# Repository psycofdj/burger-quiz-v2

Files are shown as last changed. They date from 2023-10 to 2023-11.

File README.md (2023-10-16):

<!-- markdown-toc start - Don't edit this section. Run M-x markdown-toc-refresh-toc -->
**Table of Contents**

- [Hardware](#hardware)
    - [Global Schematics](#global-schematics)
    - [Ready to solder PCB](#ready-to-solder-pcb)
- [Construction](#construction)
    - [Global design](#global-design)
    - [Components](#components)
- [Installation](#installation)

<!-- markdown-toc end -->

## Hardware

### Global Schematics

Sources for global schematics are [here](./kicad/board)

board global schematic

### Ready to solder PCB

Sources for ready-to-solder PCB are [here](./kicad/pcb)

pcb pcb schematic

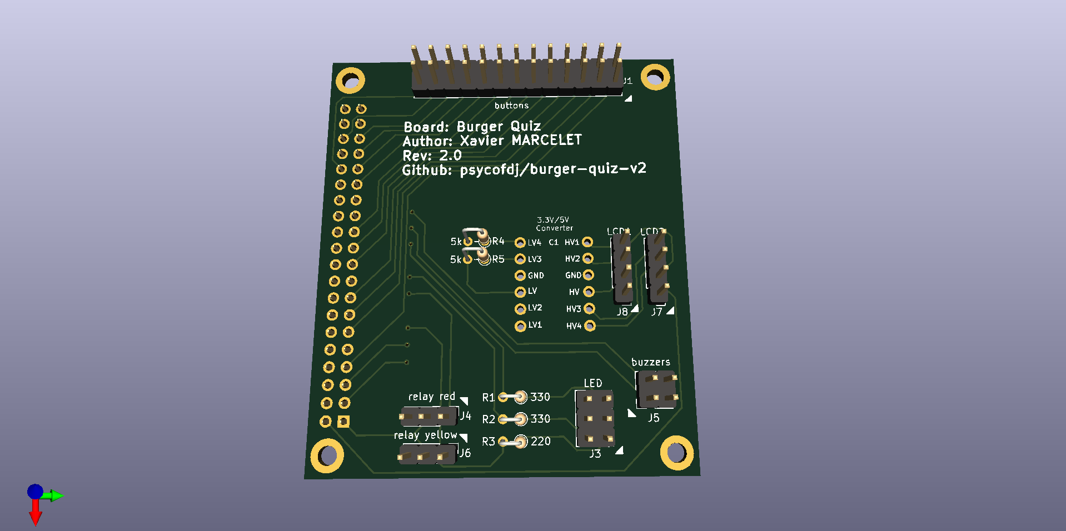
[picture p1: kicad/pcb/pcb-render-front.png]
pcb-front pcb render front


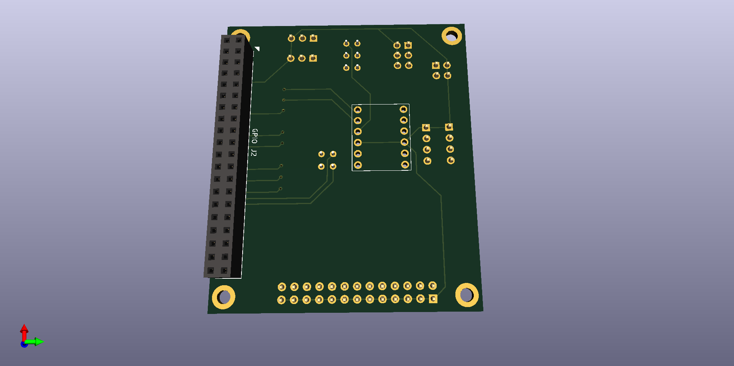
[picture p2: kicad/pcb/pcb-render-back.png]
pcb-back pcb render front


## Construction

### Global design

Sources for desk design are [here](./sketcup)

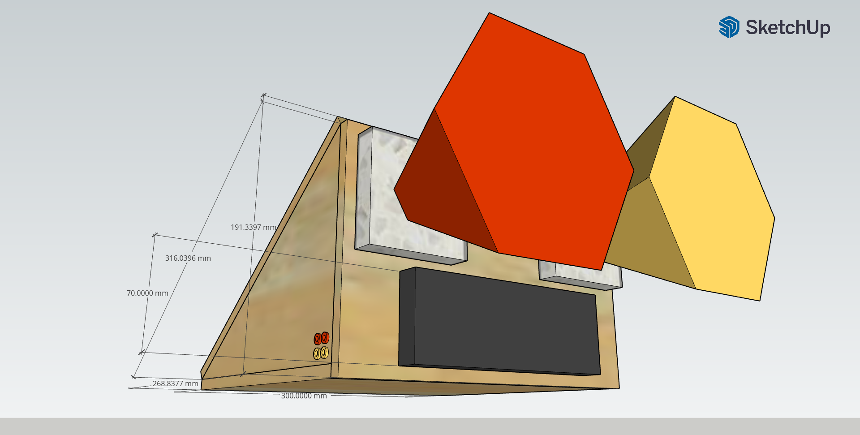
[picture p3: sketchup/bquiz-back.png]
back

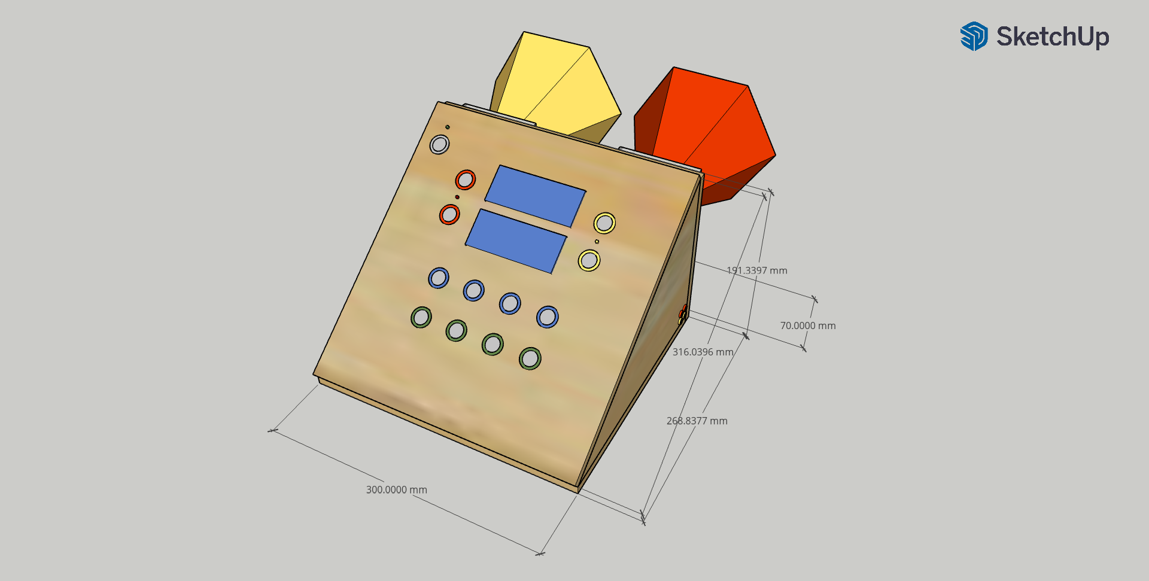
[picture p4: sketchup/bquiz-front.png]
front

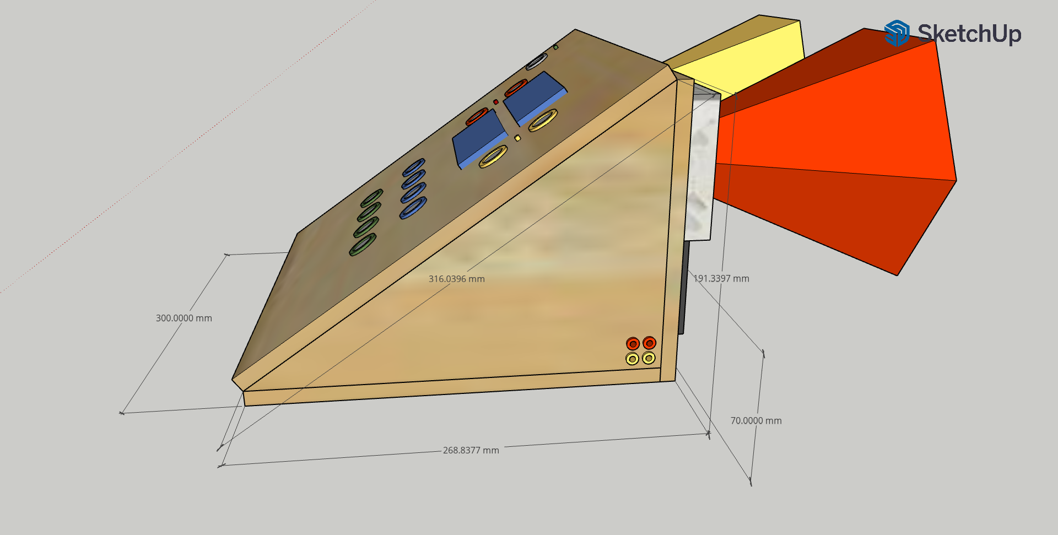
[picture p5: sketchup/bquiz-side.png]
side

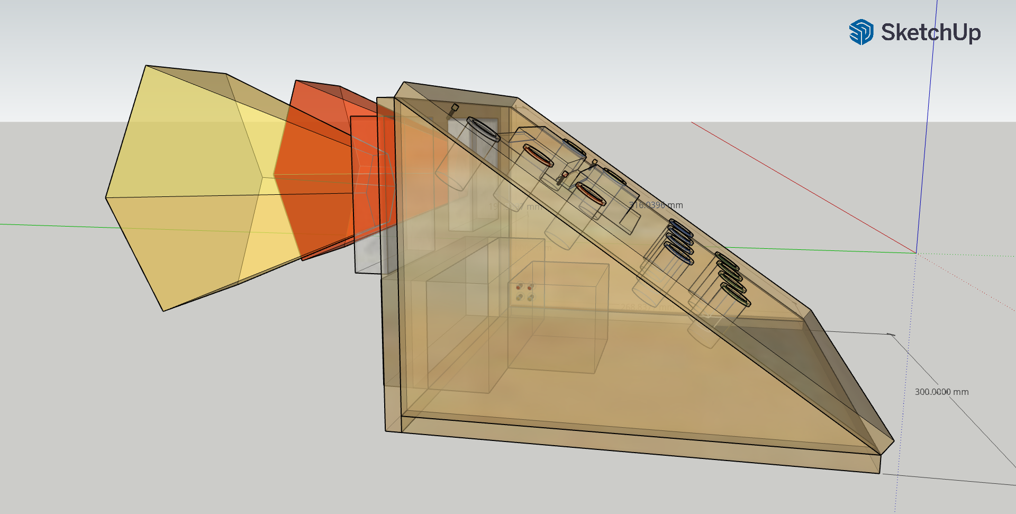
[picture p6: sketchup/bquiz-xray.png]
xray


### Components

- 22.99€,  3 x LCD displays: https://www.amazon.fr/dp/B07V5K3ZVB?ref=ppx_yo2ov_dt_b_product_details&th=1
- 8.99€,  15 x 3.3V to 5V signal converter: https://www.amazon.fr/dp/B082F6BSB5?psc=1&ref=ppx_yo2ov_dt_b_product_details
- 8.58€,   1 x LED kit: https://www.amazon.fr/dp/B08S2W74K7?ref=ppx_yo2ov_dt_b_product_details&th=1
- 10.99€,  1 x Flat cable: https://www.amazon.fr/dp/B082WZC56B?psc=1&ref=ppx_yo2ov_dt_b_product_details
- 11.99€,  1 x Connector kit: https://www.amazon.fr/dp/B089LZ14WB?psc=1&ref=ppx_yo2ov_dt_b_product_details
- 66.50€,  1 x Rasberry PI 4 model B: https://www.kubii.com/en/raspberry-pi-boards/2772-raspberry-pi-4-model-b-4gb-3272496309333.html
- 7,49 €,  1 x 16GB microSD: https://www.amazon.fr/dp/B07DVG12SF?psc=1&ref=ppx_yo2ov_dt_b_product_details
- 18.59€,  1 x USB Speader: https://www.amazon.fr/Umitive-Haut-Parleur-dOrdinateur-Compatibilit%C3%A9-Antid%C3%A9rapante/dp/B08JTRML6R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
- 38,27€, 13 x Custom made 5v LED push switches: https://fr.aliexpress.com/item/4000098893464.html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

## Installation

Sources for software are [here](./bquiz)

- Enable primary I2C port (/dev/i2c-1)

```
$ sudo raspi-config
(select 3. Interface options)
(select I5. I2C)
(select yes)
```

- Enable secondary I2C port (/dev/i2c-0)

```
cat /boot/config.txt
...
dtparam=i2c_arm=on
dtparam=i2c_vc=on
...
```

- Check I2C ports

```
 # package to test gpio port
 sudo apt install i2c-dev i2c-tools

 # check i2c ports, should have 27 on
 i2cdetect -y 1
 i2cdetect -y 0
```

- Install sound support

```
 sudo apt-get install pulseaudio pulseaudio-utils python3-vlc
```

- Configure default pulseaudio sink

```
 pactl set-default-sink alsa_output.usb-C-Media_Electronics_Inc._USB_Audio_Device-00.analog-stereo
```

- Install software as user startup service

```
 # install bquiz cli to ~/.local/bin
 python3 -m pip install .

 # install user systemd unit
 mkdir -p ~/.config/systemd/user
 ln -s $(pwd)/systemd/user/bquiz.service ~/.config/systemd/
 systemctl --user enable bquiz.service

 # run bquiz
 systemctl --user start bquiz.service
```

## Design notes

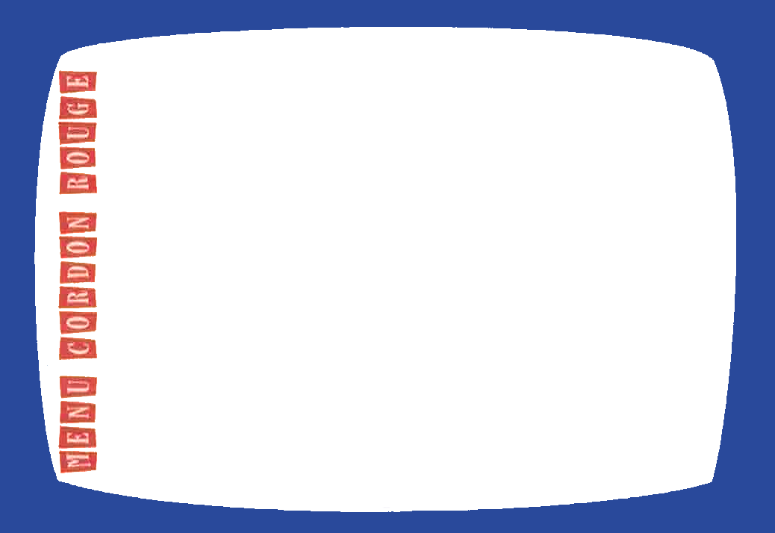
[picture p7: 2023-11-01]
bquiz/resources/menus-rouge-back.png

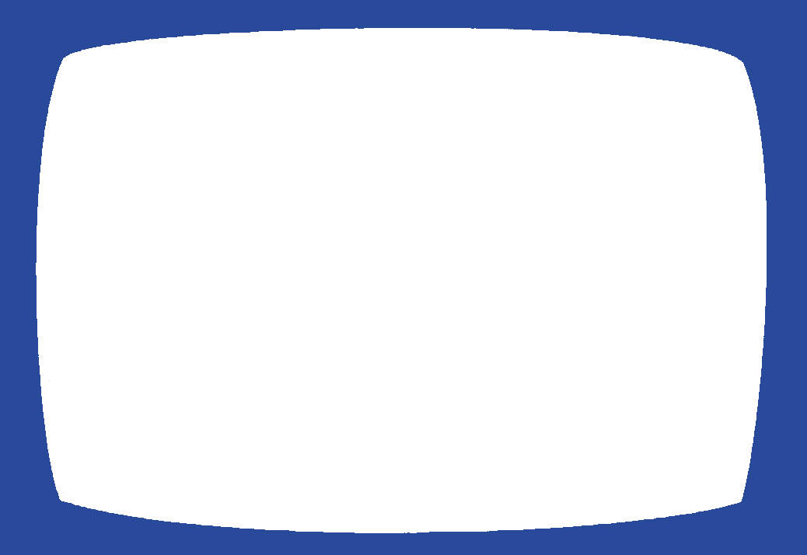
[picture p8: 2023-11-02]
bquiz/resources/base.png

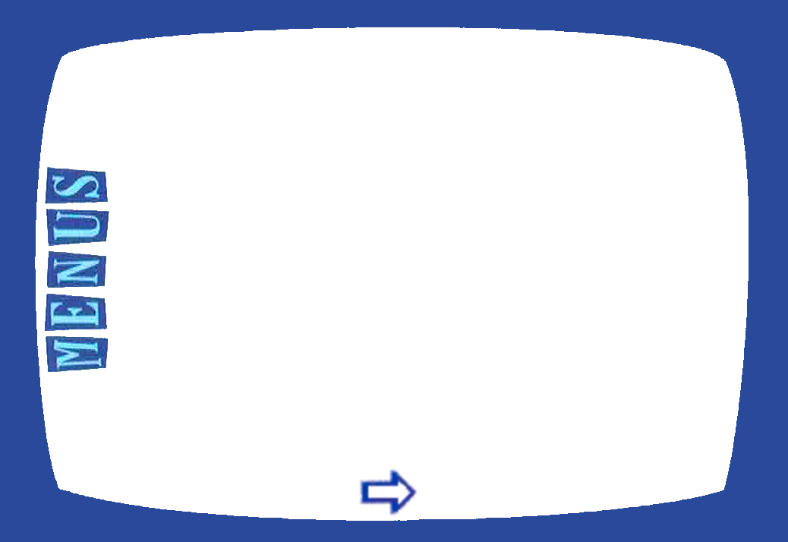
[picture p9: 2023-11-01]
bquiz/resources/menus-back-arrow.png

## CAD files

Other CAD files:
sketchup/bquiz.skp

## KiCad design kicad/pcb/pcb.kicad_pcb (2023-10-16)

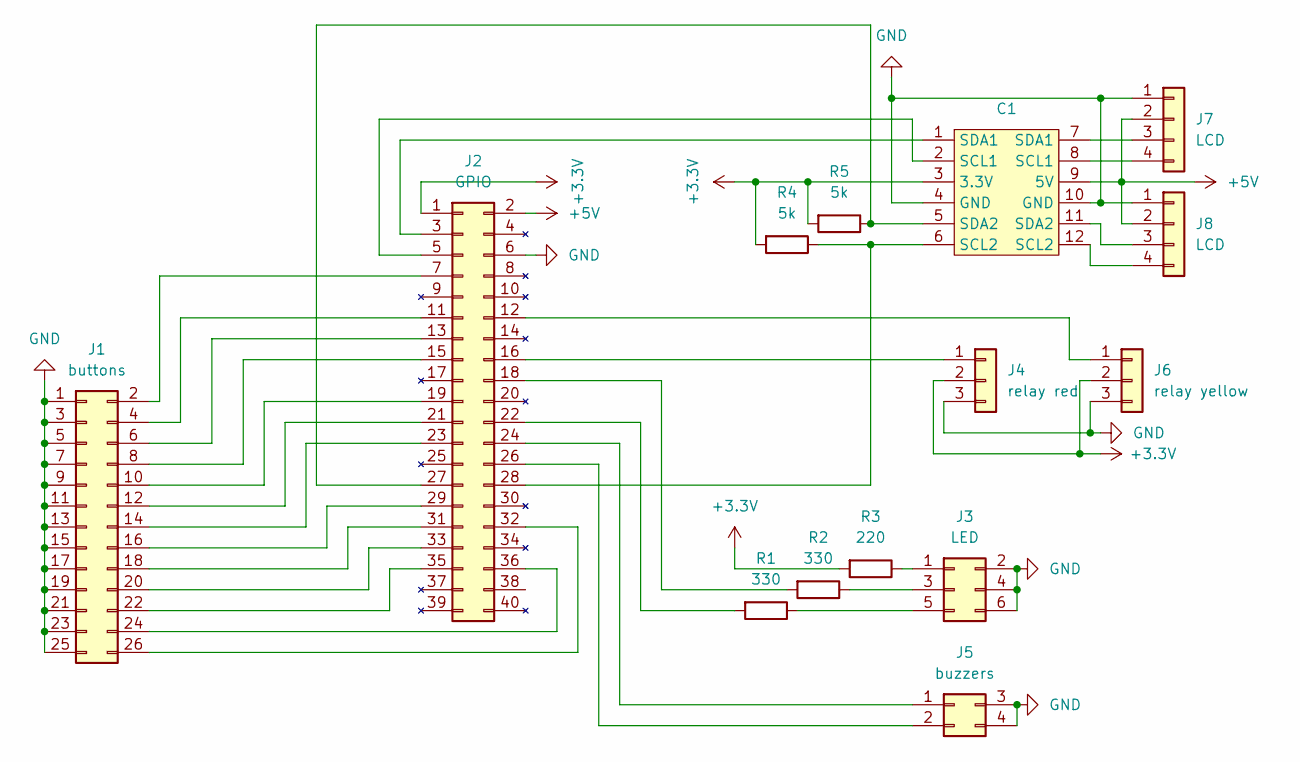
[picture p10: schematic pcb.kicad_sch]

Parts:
C1: Converter_3.3v_5v_i2c
J1: buttons; PinHeader_2x13_P2.54mm_Vertical
J2: GPIO; PinSocket_2x20_P2.54mm_Vertical
J3: LED; PinHeader_2x03_P2.54mm_Vertical
J4: relay red; PinHeader_1x03_P2.54mm_Vertical
J5: buzzers; PinHeader_2x02_P2.54mm_Vertical
J6: relay yellow; PinHeader_1x03_P2.54mm_Vertical
J7, J8: LCD; PinHeader_1x04_P2.54mm_Vertical
R1, R2: 330; R_Axial_DIN0204_L3.6mm_D1.6mm_P2.54mm_Vertical
R3: 220; R_Axial_DIN0204_L3.6mm_D1.6mm_P2.54mm_Vertical
R4, R5: 5k; R_Axial_DIN0204_L3.6mm_D1.6mm_P2.54mm_Vertical

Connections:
+3.3V: C1.3 (3.3V), J2.1 (3v3), J4.2, J6.2, R3.2, R4.2, R5.2
+5V: C1.9 (5V), J2.2 (5v0), J7.2 (VCC), J8.2 (VCC)
GND: C1.4 (GND), C1.10 (GND), J1.1 (reset), J1.3 (red+), J1.5 (red-), J1.7 (yellow+), J1.9 (yellow-), J1.11 (nuggets), J1.13 (selpoivre), J1.15 (menus), J1.17 (addition), J1.19 (sample1), J1.21 (sample2), J1.23 (sample3), J1.25 (sample4), J2.6 (GND), J3.2, J3.4, J3.6, J4.3, J5.3, J5.4, J6.3, J7.1 (GND), J8.1 (GND)
unnamed: C1.2 (SCL1), J2.5 (SCL1)
unnamed: C1.6 (SCL2), J2.28 (SCL2), R4.1
unnamed: C1.1 (SDA1), J2.3 (SDA1)
unnamed: C1.5 (SDA2), J2.27 (SDA2), R5.1
unnamed: J1.14 (selpoivre), J2.23 (wip14)
unnamed: J1.16 (menus), J2.29 (wip21)
unnamed: J1.18 (addition), J2.31 (wip22)
unnamed: J1.20 (sample1), J2.33 (wip23)
unnamed: J1.22 (sample2), J2.35 (wip24)
unnamed: J1.4 (red+), J2.11 (wpi0)
unnamed: J2.12 (wpi1), J6.1
unnamed: J1.6 (red-), J2.13 (wpi2)
unnamed: J1.8 (yellow+), J2.15 (wpi3)
unnamed: J2.16 (wpi4), J4.1
unnamed: J2.18 (wpi5), R2.2
unnamed: J2.22 (wpi6), R1.2
unnamed: J1.2 (reset), J2.7 (wpi7)
unnamed: J2.24 (wpi10), J5.1
unnamed: J2.26 (wpi11), J5.2
unnamed: J1.10 (yellow-), J2.19 (wpi12)
unnamed: J1.12 (nuggets), J2.21 (wpi13)
unnamed: J1.26 (sample4), J2.32 (wpi26)
unnamed: J1.24 (sample3), J2.36 (wpi27)
unnamed: J3.1, R3.1
unnamed: J3.3, R2.1
unnamed: J3.5, R1.1
unnamed: C1.8 (SCL1), J7.4 (SCL)
unnamed: C1.7 (SDA1), J7.3 (SDA)
unnamed: C1.12 (SCL2), J8.4 (SCL)
unnamed: C1.11 (SDA2), J8.3 (SDA)

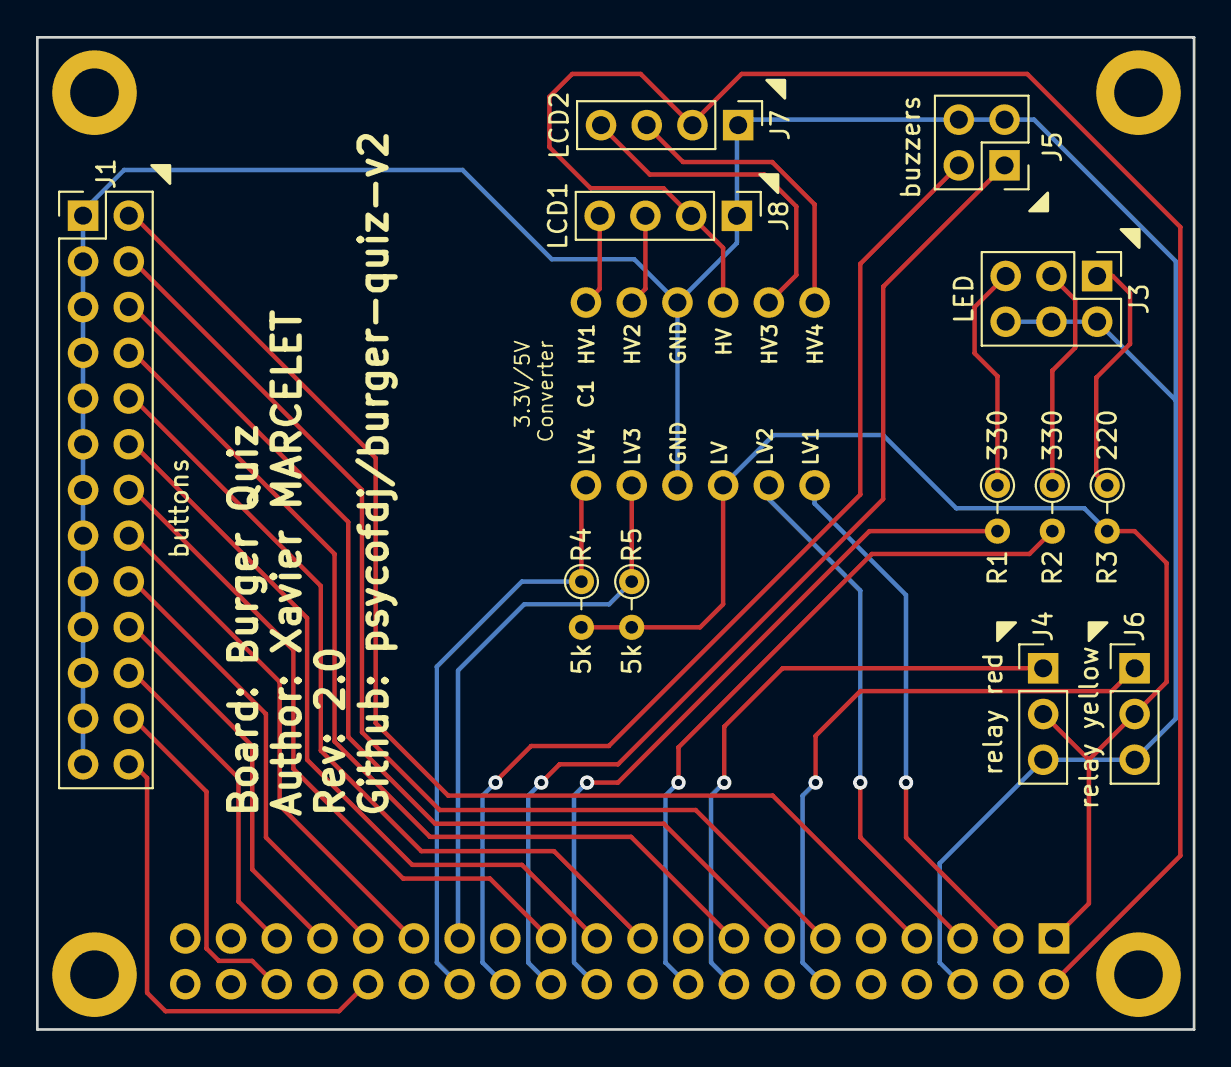
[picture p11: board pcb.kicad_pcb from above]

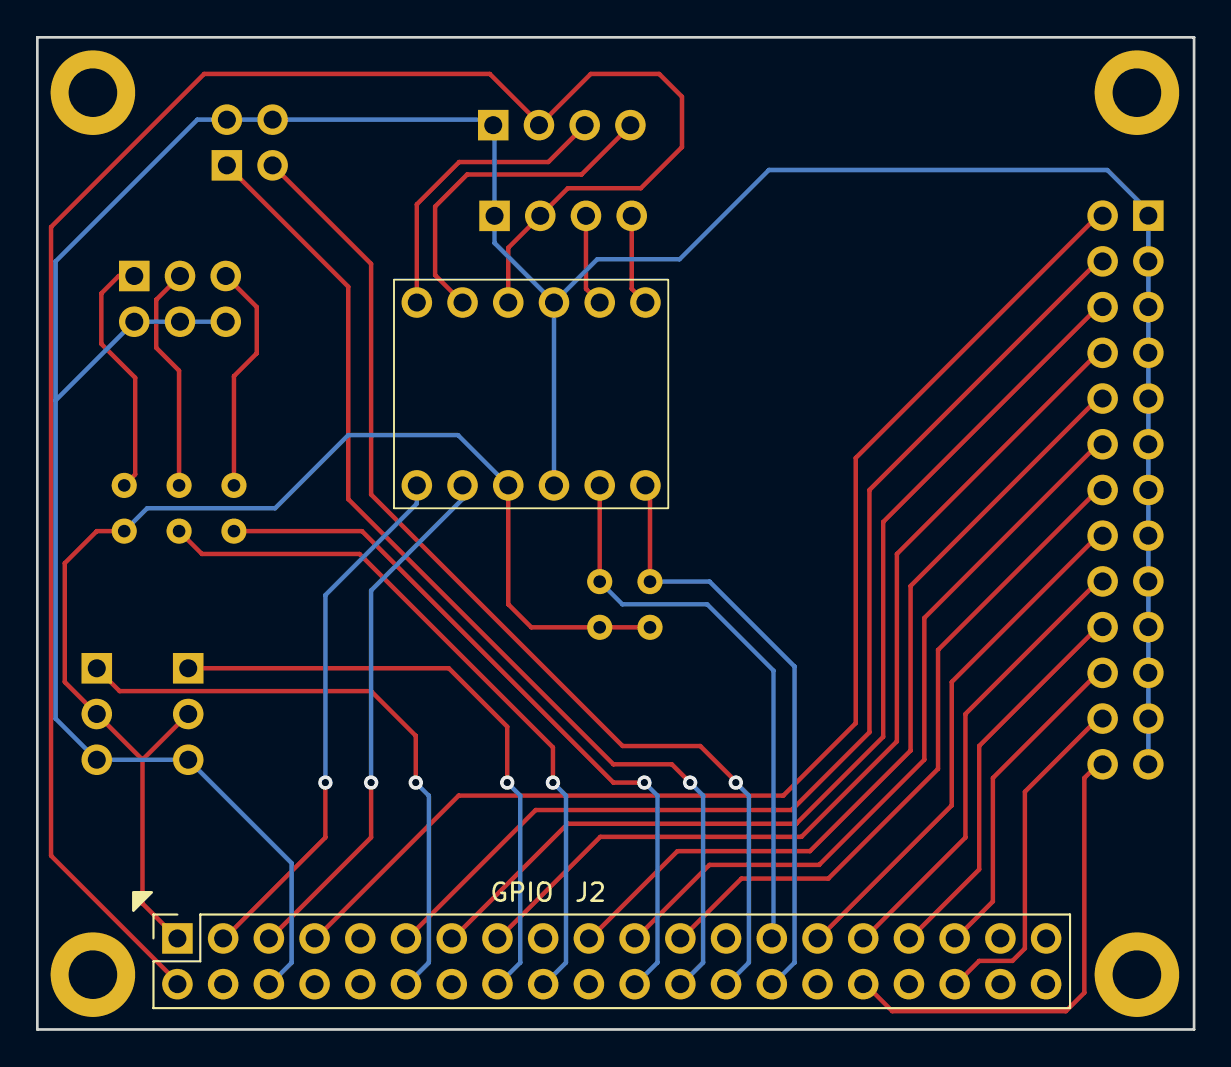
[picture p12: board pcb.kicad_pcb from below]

Board: 2 copper layers, 64.3 x 55.1 mm, 14 parts (2 on the bottom side), 33 nets.

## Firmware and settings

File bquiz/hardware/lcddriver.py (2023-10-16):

import sys
sys.path.append("./lib")

from . import i2c_lib
from time import *

# LCD Address
ADDRESS = 0x27

# commands
LCD_CLEARDISPLAY = 0x01
LCD_RETURNHOME = 0x02
LCD_ENTRYMODESET = 0x04
LCD_DISPLAYCONTROL = 0x08
LCD_CURSORSHIFT = 0x10
LCD_FUNCTIONSET = 0x20
LCD_SETCGRAMADDR = 0x40
LCD_SETDDRAMADDR = 0x80

# flags for display entry mode
LCD_ENTRYRIGHT = 0x00
LCD_ENTRYLEFT = 0x02
LCD_ENTRYSHIFTINCREMENT = 0x01
LCD_ENTRYSHIFTDECREMENT = 0x00

# flags for display on/off control
LCD_DISPLAYON = 0x04
LCD_DISPLAYOFF = 0x00
LCD_CURSORON = 0x02
LCD_CURSOROFF = 0x00
LCD_BLINKON = 0x01
LCD_BLINKOFF = 0x00

# flags for display/cursor shift
LCD_DISPLAYMOVE = 0x08
LCD_CURSORMOVE = 0x00
LCD_MOVERIGHT = 0x04
LCD_MOVELEFT = 0x00

# flags for function set
LCD_8BITMODE = 0x10
LCD_4BITMODE = 0x00
LCD_2LINE = 0x08
LCD_1LINE = 0x00
LCD_5x10DOTS = 0x04
LCD_5x8DOTS = 0x00

# flags for backlight control
LCD_BACKLIGHT = 0x08
LCD_NOBACKLIGHT = 0x00

En = 0b00000100 # Enable bit
Rw = 0b00000010 # Read/Write bit
Rs = 0b00000001 # Register select bit

class lcd:
   #initializes objects and lcd
   def __init__(self, port=1):
      self.lcd_device = i2c_lib.i2c_device(ADDRESS, port)
      self.lcd_write(0x03)
      self.lcd_write(0x03)
      self.lcd_write(0x03)
      self.lcd_write(0x02)
      self.lcd_write(LCD_FUNCTIONSET | LCD_2LINE | LCD_5x8DOTS | LCD_4BITMODE)
      self.lcd_write(LCD_DISPLAYCONTROL | LCD_DISPLAYON)
      self.lcd_write(LCD_CLEARDISPLAY)
      self.lcd_write(LCD_ENTRYMODESET | LCD_ENTRYLEFT)
      sleep(0.2)

   # clocks EN to latch command
   def lcd_strobe(self, data):
      self.lcd_device.write_cmd(data | En | LCD_BACKLIGHT)
      sleep(.0005)
      self.lcd_device.write_cmd(((data & ~En) | LCD_BACKLIGHT))
      sleep(.0001)

   def lcd_write_four_bits(self, data):
      self.lcd_device.write_cmd(data | LCD_BACKLIGHT)
      self.lcd_strobe(data)

   # write a command to lcd
   def lcd_write(self, cmd, mode=0):
      self.lcd_write_four_bits(mode | (cmd & 0xF0))
      self.lcd_write_four_bits(mode | ((cmd << 4) & 0xF0))

   #turn on/off the lcd backlight
   def lcd_backlight(self, state):
      if state in ("on","On","ON"):
         self.lcd_device.write_cmd(LCD_BACKLIGHT)
      elif state in ("off","Off","OFF"):
         self.lcd_device.write_cmd(LCD_NOBACKLIGHT)
      else:
         print("Unknown State!")

   # put string function
   def lcd_display_string(self, string, line):
      if line == 1:
         self.lcd_write(0x80)
      if line == 2:
         self.lcd_write(0xC0)
      if line == 3:
         self.lcd_write(0x94)
      if line == 4:
         self.lcd_write(0xD4)

      for char in string:
         self.lcd_write(ord(char), Rs)

   # clear lcd and set to home
   def lcd_clear(self):
      self.lcd_write(LCD_CLEARDISPLAY)
      self.lcd_write(LCD_RETURNHOME)

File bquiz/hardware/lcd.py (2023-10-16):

import datetime
import math

from . import lcddriver

class LCD:
    class Caterpillar:
        LINEOFFSET = [0x80, 0xC0, 0x94, 0xD4]
        MASK = {
            "frame1": [
                "10010010010010010010",
                "0                  0",
                "0                  1",
                "10010010010010010010",
            ],
            "frame2": [
                "01001001001001001001",
                "0                  0",
                "1                  0",
                "00100100100100100101",
            ],
            "frame3": [
                "00100100100100100100",
                "1                  1",
                "0                  0",
                "01001001001001001010",
            ],
        }
        def __init__(self, delay_ms=150):
            self.delay_ms = delay_ms
            self.frame = "frame1"
            self.start_time = datetime.datetime.now()

        def display_frame(self, handler):
            handler.lcd_write(lcddriver.LCD_RETURNHOME)
            for c_idx, c_mask in enumerate(LCD.Caterpillar.MASK[self.frame]):
                offset = LCD.Caterpillar.LINEOFFSET[c_idx]
                for c_addr, c_char in enumerate(c_mask):
                    handler.lcd_write(offset + c_addr)
                    if c_char == "1":
                        handler.lcd_write(0b00101010, lcddriver.Rs)
                    elif c_char == "0":
                        handler.lcd_write(ord(" "), lcddriver.Rs)

        def next_frame(self):
            if self.frame == "frame1":
                self.frame = "frame2"
            elif self.frame == "frame2":
                self.frame = "frame3"
            elif self.frame == "frame3":
                self.frame = "frame1"
            self.start_time = self.start_time + datetime.timedelta(milliseconds=self.delay_ms)

        def update(self, handler):
            delta = datetime.datetime.now() - self.start_time
            deltaMs = delta / datetime.timedelta(milliseconds=1)
            if deltaMs > self.delay_ms:
                self.next_frame()
                self.display_frame(handler)

    class Line:
        LEFT = 0
        RIGHT = 1
        def __init__(self, text="", justify=LEFT, speed=3):
            self.cursor = 0
            self.text = text
            self.justify = justify
            self.speed = speed
            self.last = datetime.datetime.now()

        def draw(self, handler, idx):
            fmt = "%20s"
            if self.justify == LCD.Line.LEFT:
                fmt = "%- 20s"
            val = fmt % self.text[self.cursor-20:self.cursor]
            handler.lcd_display_string(val, idx + 1)
            self.last = datetime.datetime.now()

        def update(self, handler, idx):
            if self.cursor >= len(self.text):
                return
            if self.cursor == 0:
                self.cursor += 20
                self.draw(handler, idx)
            else:
                elapsed = datetime.datetime.now() - self.last
                elapsedMs = elapsed / datetime.timedelta(milliseconds=1)
                nb = math.floor(float(elapsedMs) * float(self.speed) / float(1000))
                if nb > 0:
                    self.cursor += nb
                    self.draw(handler, idx)

    def __init__(self, i2cPort):
        self.lines = [ LCD.Line(), LCD.Line(), LCD.Line(), LCD.Line() ]
        self.handler = lcddriver.lcd(i2cPort)
        self.bg_off()
        self.caterpillar = None


    def set_text(self, text):
        lines = [[]]
        words = text.split(" ")
        for word in words:
            w = len(word)
            l = len(" ".join(lines[-1]))
            if l + w < 20:
                lines[-1].append(word)
            else:
                lines.append([word])
        self.handler.lcd_clear()
        for idx, words in enumerate(lines):
            if idx > 3:
                break
            self.set_line(idx, " ".join(words))

    def set_line(self, idx, text="", justify=Line.LEFT, speed=3):
        self.bg_on()
        self.lines[idx] = LCD.Line(text, justify, speed)

    def bg_off(self):
        self.handler.lcd_backlight("off")

    def bg_on(self):
        self.handler.lcd_backlight("on")

    def add_caterpillar(self):
        self.caterpillar = LCD.Caterpillar()

    def update(self):
        for c_idx, c_line in enumerate(self.lines):
            c_line.update(self.handler, c_idx)
        if self.caterpillar is not None:
            self.caterpillar.update(self.handler)

    def finalize(self):
        self.bg_off()

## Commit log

2023-10-16 add skethup sources
    [bquiz.skp]
2023-10-16 update pcb
    [pcb.kicad_pcb]
